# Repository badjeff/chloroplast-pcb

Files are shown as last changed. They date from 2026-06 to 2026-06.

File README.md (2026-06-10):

# chloroplast

A nRF52840 controller with the [Ebyte E73-2G4M08S1C module](https://www.cdebyte.com/products/E73-2G4M08S1C), [TI BQ25186DLHR](https://www.ti.com/product/BQ25186/part-details/BQ25186DLHR), and [TI TPS7A0233PDBVR](https://www.ti.com/product/TPS7A02/part-details/TPS7A0233PDBVR).

<p float="left">
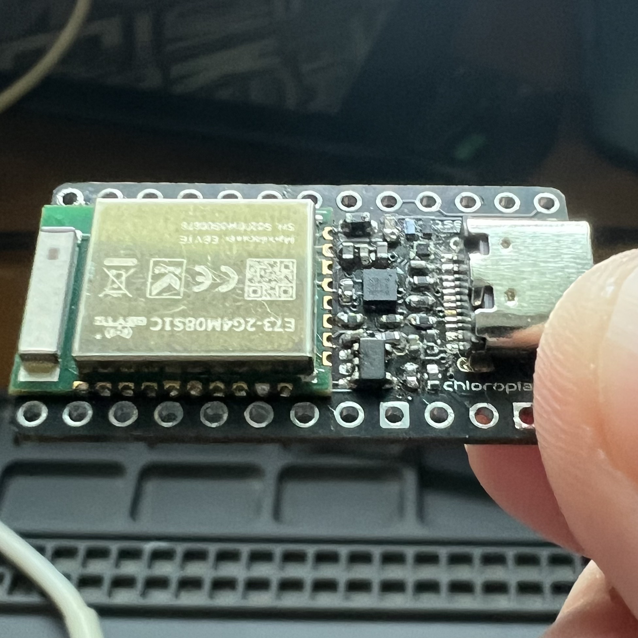
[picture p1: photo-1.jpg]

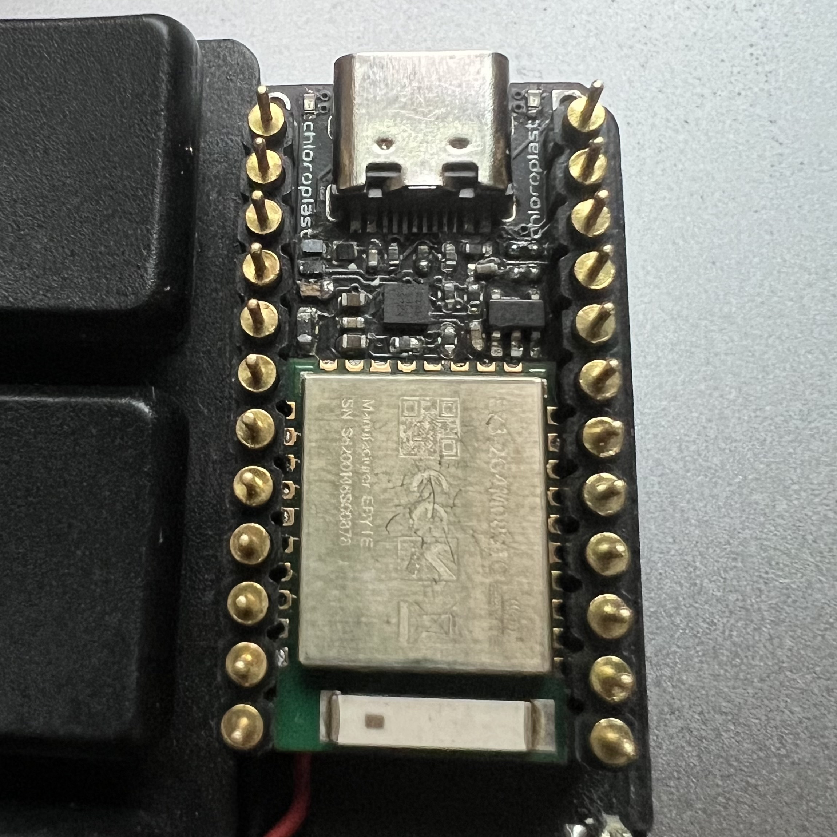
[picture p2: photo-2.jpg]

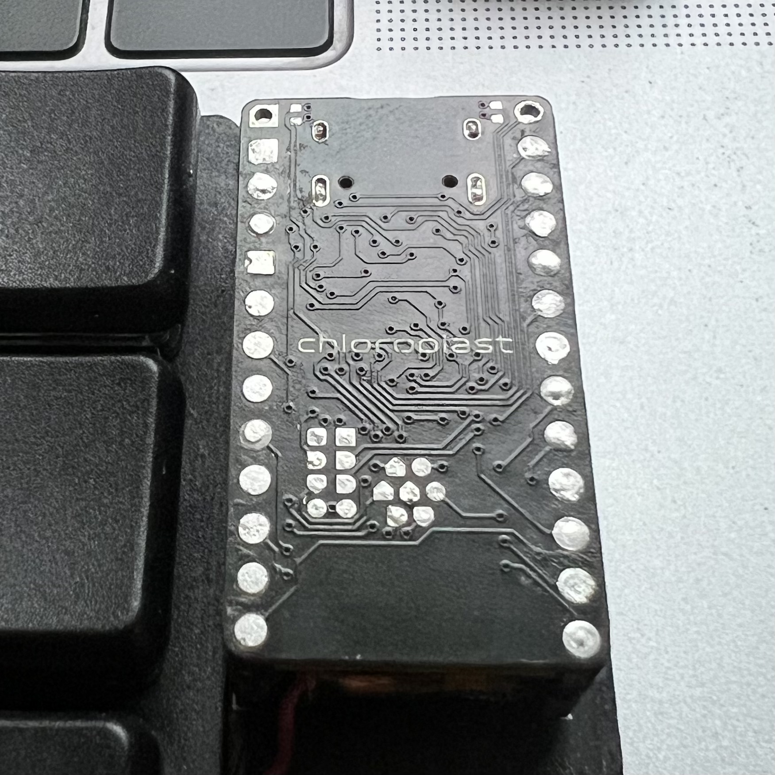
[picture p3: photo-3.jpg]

</p>

## PCB

Online preview avaliable [here](https://kicanvas.org/?github=https%3A%2F%2Fgithub.com%2Fbadjeff%2Fchloroplast-pcb), powered by [KiCanvas](https://github.com/theacodes/kicanvas).

<p float="left">
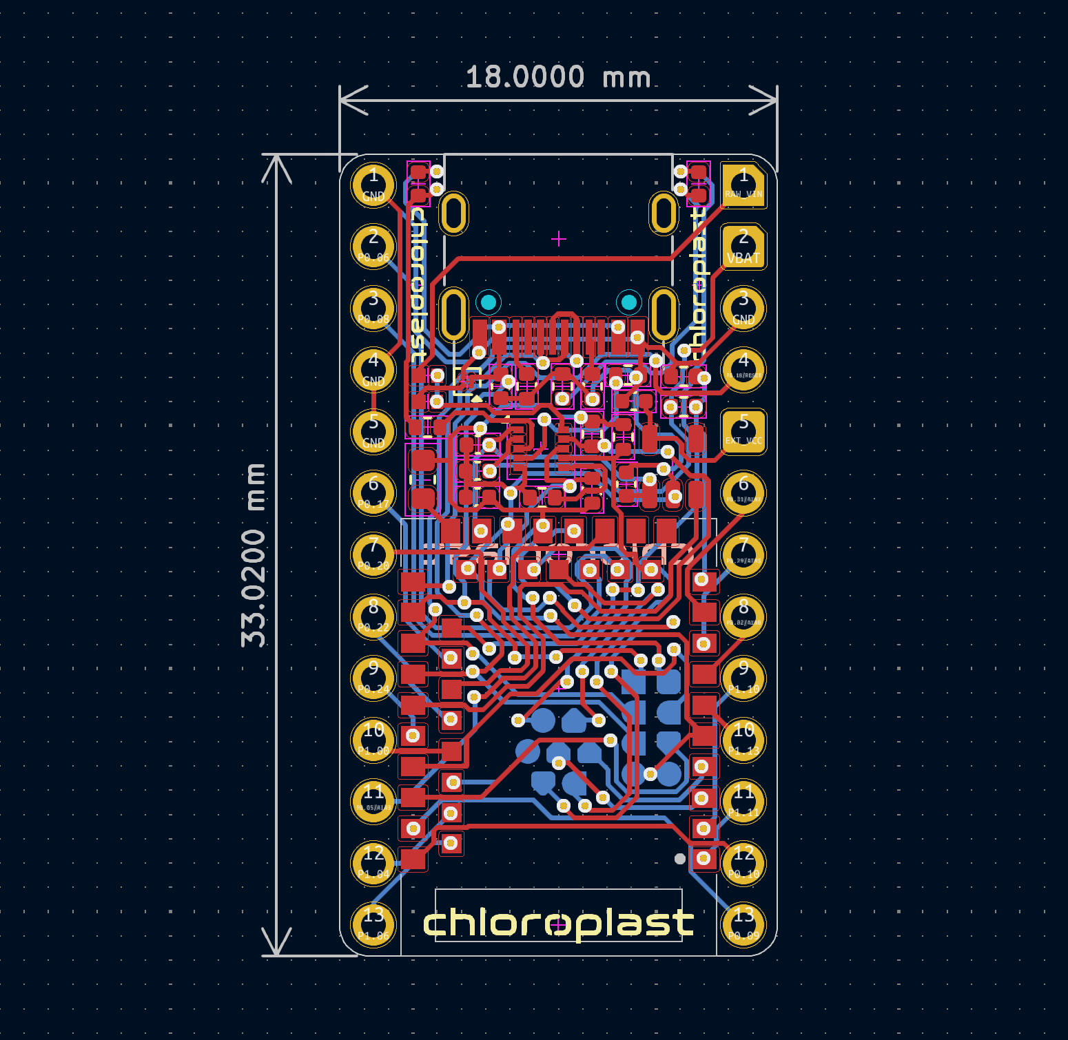
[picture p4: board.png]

</P>

*Figure 1: PCB edgecuts dimension*

<p float="left">
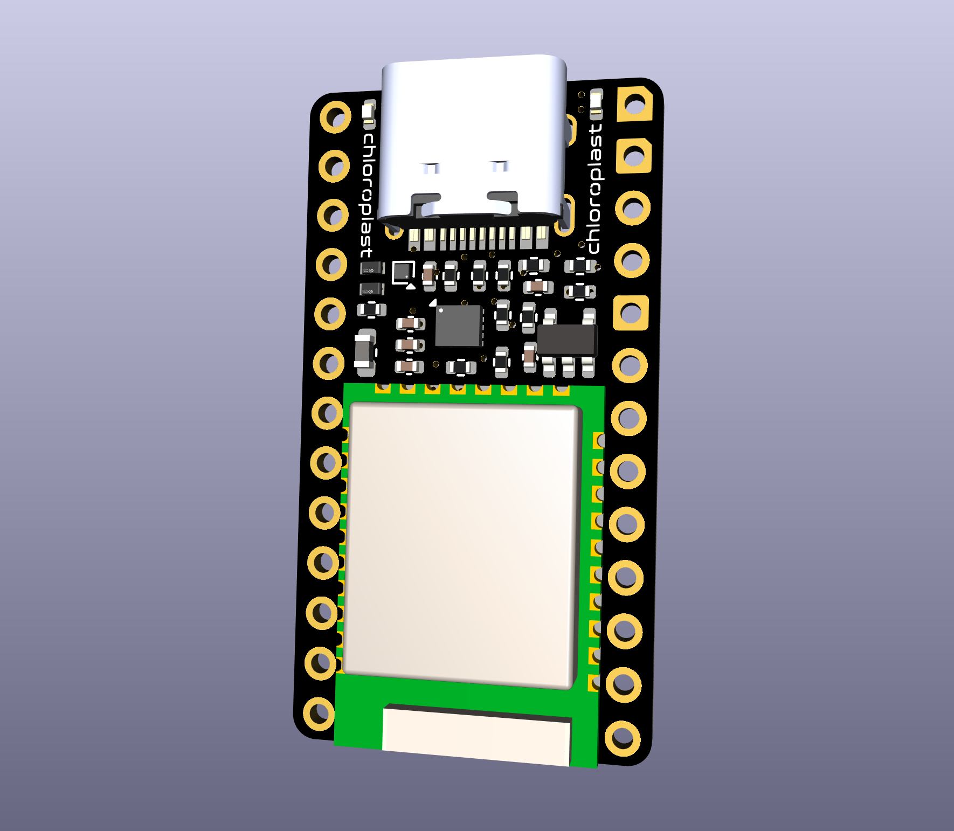
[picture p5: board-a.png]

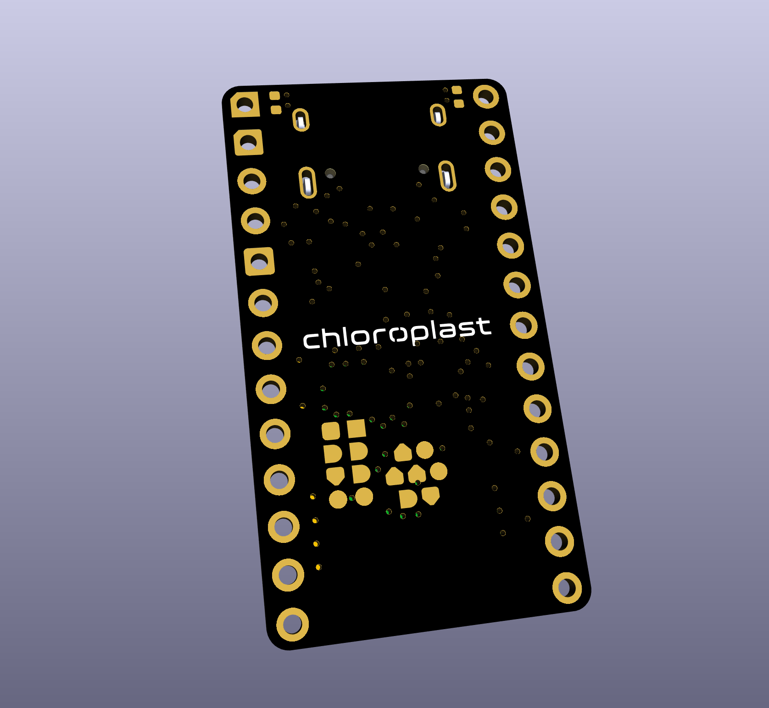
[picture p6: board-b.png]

</p>

*Figure 2: PCB 3D View - 1.0mm FR4*

<p float="left">
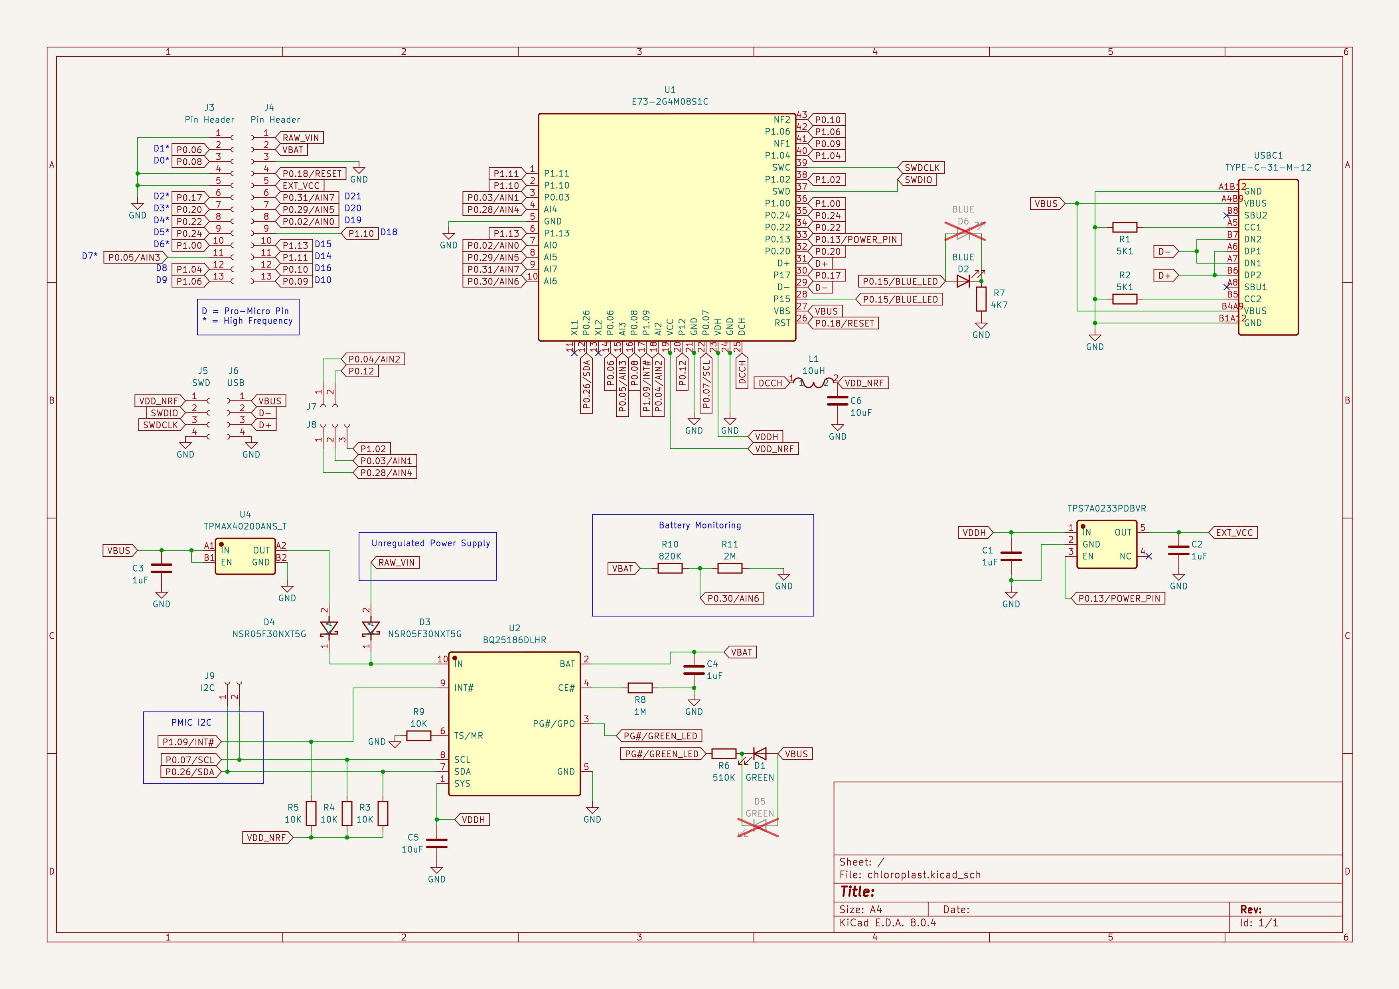
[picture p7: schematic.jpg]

</p>

*Figure 3: Schematic*

### BOM

|Designator|Footprint|Quantity|Value|LCSC Part #|
|-|-|-|-|-|
|C1,C2,C3,C4|0402|4|1uF|C52923|
|C5,C6|0402|2|10uF|C15525|
|D1|0402|1|GREEN LED|C20608784|
|D2|0402|1|BLUE LED|C434447|
|D3,D4|0402|2|NSR05F30NXT5G|C604339|
|L1|0603|1|10uH|C76798|
|R1,R2|0402|2|5K1|C25905|
|R3,R4,R5,R9|0402|4|10K|C25744|
|R6|0402|1|510K|C11616|
|R7|0402|1|4K7|C25900|
|R8|0402|1|1M|C2909328|
|R10|0402|1|820K|C2909386|
|R11|0402|1|2M|C2930015|
|U1|E73-2G4M08S1C|1|E73-2G4M08S1C|C356849|
|U2|DFN-10_2x2mm_P0.4mm|1|BQ25186DLHR|C44639442|
|U3|SOT-23-5|1|TPS7A0233PDBVR|C2887324|
|U4|WLCSP-4L|1|TPMAX40200ANS_T|C47117620|
|USBC1|USB_C_Receptacle|1|TYPE-C-31-M-12|C165948|

- SMD 0402 (Imperial) aka 1005 Metric.
- Alternative LED pads (D5,D6) are layouted on back.

### Board Characteristics

- Copper layer count: 2
- Board thickness: 1.0 mm
- Board overall dimensions: 18.0 x 33.02 mm

### Bootloader

This board uses Adafruit Bootloader. The board folder could be found at [here](https://github.com/adafruit/Adafruit_nRF52_Bootloader/compare/master...badjeff:Adafruit_nRF52_Bootloader:master). Bootloader flashing is recommended to follow the comprehensive guide on [joric/nrfmicro/wiki/Bootloader](https://github.com/joric/nrfmicro/wiki/Bootloader).

### Zephye/ZMK Board Config

Zephyr and ZMK board config could be found in [chloroplast-zmk-module](https://github.com/badjeff/chloroplast-zmk-module). ZMK sheild example could be found in [shields/chlorotaro34](https://github.com/badjeff/zmk-config/tree/a3d11110aed00859894f039f29c2347270b4b8b8/boards/shields/chlorotaro34).

## License

Available under the [CERN-OHL-P v2](/LICENSE) permissive license.

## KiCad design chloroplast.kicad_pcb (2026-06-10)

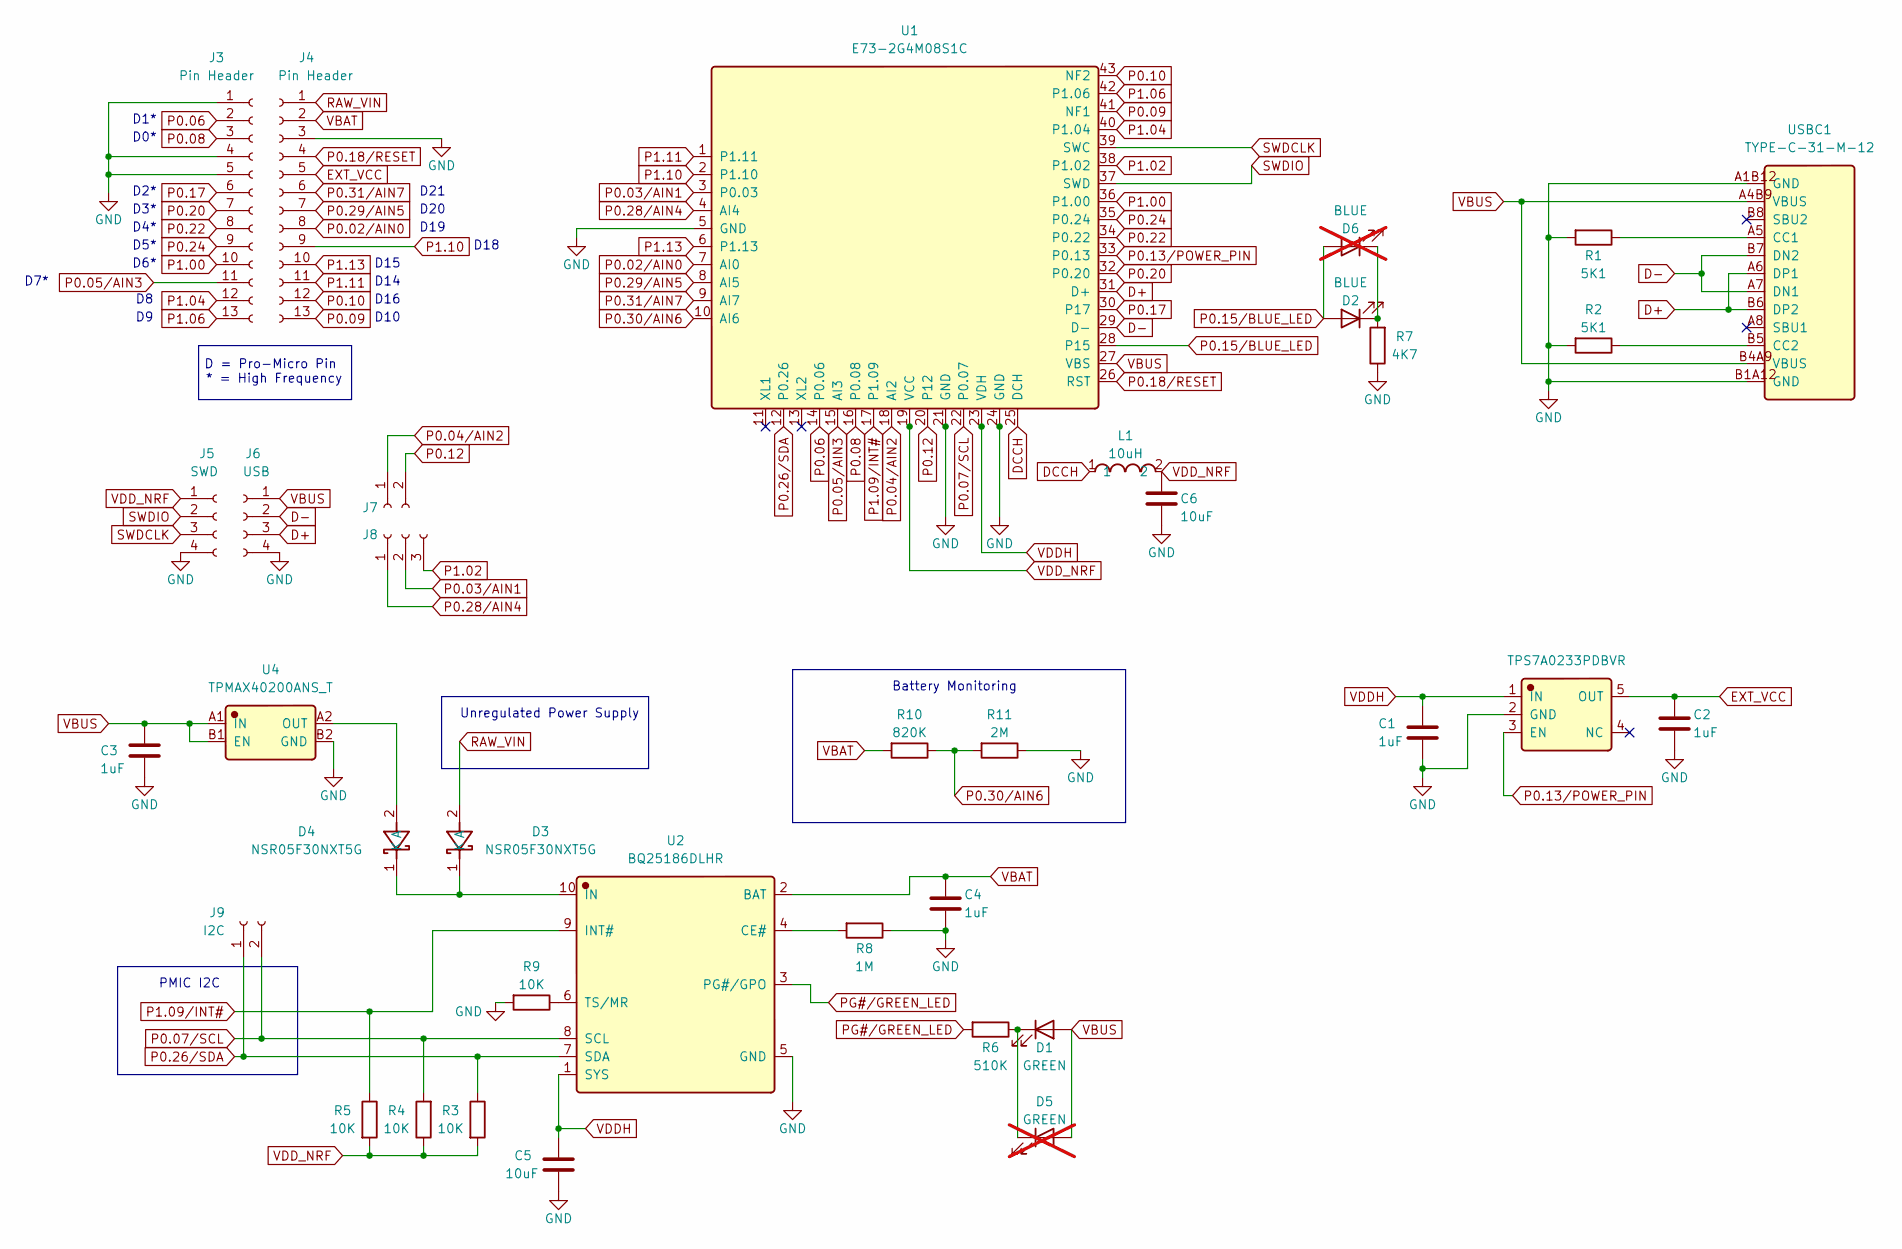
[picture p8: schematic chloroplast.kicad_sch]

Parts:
C1, C2, C3, C4: 1uF; C_0402_1005Metric; LCSC C52923
C5, C6: 10uF; C_0402_1005Metric; LCSC C15525
D1: GREEN; LED_0402_1005Metric; LCSC C20608784
D2: BLUE; LED_0402_1005Metric; LCSC C434447
D3, D4: NSR05F30NXT5G; Manufacturer Part NSR05F30NXT5G; LCSC C604339
D5: GREEN; LED_0402_1005Metric; LCSC C20608784; not fitted
D6: BLUE; LED_0402_1005Metric; LCSC C434447; not fitted
J3, J4: Pin Header; PinHeader_1x13_P2.54mm_Vertical
J5: SWD; PinHeader_1x04_P1.27mm_Vertical
J6: USB; PinHeader_1x04_P1.27mm_Vertical
J7: Conn_01x02_Socket; PinHeader_1x02_P1.27mm_Vertical
J8: Conn_01x04_Socket; PinHeader_1x03_P1.27mm_Vertical
J9: I2C; PinHeader_1x02_P1.27mm_Vertical
L1: 10uH; L_0603_1608Metric; Manufacturer Part MLZ1608M100WT000; LCSC C76798
R1, R2: 5K1; R_0402_1005Metric; LCSC C25905
R3, R4, R5, R9: 10K; R_0402_1005Metric; LCSC C25744
R6: 510K; R_0402_1005Metric; LCSC C11616
R7: 4K7; R_0402_1005Metric; LCSC C25900
R8: 1M; R_0402_1005Metric; LCSC C2909328
R10: 820K; R_0402_1005Metric; LCSC C2909386
R11: 2M; R_0402_1005Metric; LCSC C2930015
U1: E73-2G4M08S1C; Manufacturer Part E73-2G4M08S1C; LCSC C356849
U2: BQ25186DLHR; DFN-10_2x2mm_P0.4mm; Manufacturer Part BQ25186DLHR; LCSC C44639442
U3: TPS7A0233PDBVR; SOT-23-5; Manufacturer Part TPS7A0233PDBVR; LCSC C2887324
U4: TPMAX40200ANS_T; WLCSP-4_0.64x0.64mm_P0.35mm; Manufacturer Part TPMAX40200ANS+T; LCSC C47117620
USBC1: TYPE-C-31-M-12; USB_C_Receptacle_HRO_TYPE-C-31-M-12; Manufacturer Part TYPE-C-31-M-12; LCSC C165948

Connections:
D+: J6.3, U1.31 (D+), USBC1.A6 (DP1), USBC1.B6 (DP2)
D-: J6.2, U1.29 (D-), USBC1.A7 (DN1), USBC1.B7 (DN2)
DCCH: L1.1, U1.25 (DCH)
EXT_VCC: C2.1, J4.5, U3.5 (OUT)
GND: C1.2, C2.2, C3.2, C4.2, C5.2, C6.2, J3.1, J3.4, J3.5, J4.3, J5.4, J6.4, R1.2, R2.2, R7.1, R8.1, R9.2, R11.1, U1.5 (GND), U1.21 (GND), U1.24 (GND), U2.5 (GND), U3.2 (GND), U4.B2 (GND), USBC1.A1B12 (GND), USBC1.B1A12 (GND)
unnamed: D1.1 (K), D5.1 (K), R6.1
unnamed: D2.1 (K), D6.1 (K), R7.2
unnamed: D3.1 (K), D4.1 (K), U2.10 (IN)
unnamed: D4.2 (A), U4.A2 (OUT)
unnamed: R8.2, U2.4 (CE#)
unnamed: R9.1, U2.6 (TS/MR)
unnamed: R1.1, USBC1.A5 (CC1)
unnamed: R2.1, USBC1.B5 (CC2)
P0.02/AIN0: J4.8, U1.7 (AI0)
P0.03/AIN1: J8.2, U1.3 (P0.03)
P0.04/AIN2: J7.1, U1.18 (AI2)
P0.05/AIN3: J3.11, U1.15 (AI3)
P0.06: J3.2, U1.14 (P0.06)
P0.07/SCL: J9.2, R4.2, U1.22 (P0.07), U2.8 (SCL)
P0.08: J3.3, U1.16 (P0.08)
P0.09: J4.13, U1.41 (NF1)
P0.10: J4.12, U1.43 (NF2)
P0.12: J7.2, U1.20 (P12)
P0.13/POWER_PIN: U1.33 (P0.13), U3.3 (EN)
P0.15/BLUE_LED: D2.2 (A), D6.2 (A), U1.28 (P15)
P0.17: J3.6, U1.30 (P17)
P0.18/RESET: J4.4, U1.26 (RST)
P0.20: J3.7, U1.32 (P0.20)
P0.22: J3.8, U1.34 (P0.22)
P0.24: J3.9, U1.35 (P0.24)
P0.26/SDA: J9.1, R3.1, U1.12 (P0.26), U2.7 (SDA)
P0.28/AIN4: J8.1, U1.4 (AI4)
P0.29/AIN5: J4.7, U1.8 (AI5)
P0.30/AIN6: R10.1, R11.2, U1.10 (AI6)
P0.31/AIN7: J4.6, U1.9 (AI7)
P1.00: J3.10, U1.36 (P1.00)
P1.02: J8.3, U1.38 (P1.02)
P1.04: J3.12, U1.40 (P1.04)
P1.06: J3.13, U1.42 (P1.06)
P1.09/INT#: R5.1, U1.17 (P1.09), U2.9 (INT#)
P1.10: J4.9, U1.2 (P1.10)
P1.11: J4.11, U1.1 (P1.11)
P1.13: J4.10, U1.6 (P1.13)
PG#/GREEN_LED: R6.2, U2.3 (PG#/GPO)
RAW_VIN: D3.2 (A), J4.1
SWDCLK: J5.3, U1.39 (SWC)
SWDIO: J5.2, U1.37 (SWD)
VBAT: C4.1, J4.2, R10.2, U2.2 (BAT)
VBUS: C3.1, D1.2 (A), D5.2 (A), J6.1, U1.27 (VBS), U4.A1 (IN), U4.B1 (EN), USBC1.A4B9 (VBUS), USBC1.B4A9 (VBUS)
VDDH: C1.1, C5.1, U1.23 (VDH), U2.1 (SYS), U3.1 (IN)
VDD_NRF: C6.1, J5.1, L1.2, R3.2, R4.1, R5.2, U1.19 (VCC)

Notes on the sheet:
Unregulated Power Supply
D20
D19
D18
Battery Monitoring
D21
D14
D6*
D15
D5*
D3*
D16
D1*
D = Pro-Micro Pin * = High Frequency
D4*
D0*
D2*
D10
PMIC I2C
D7*

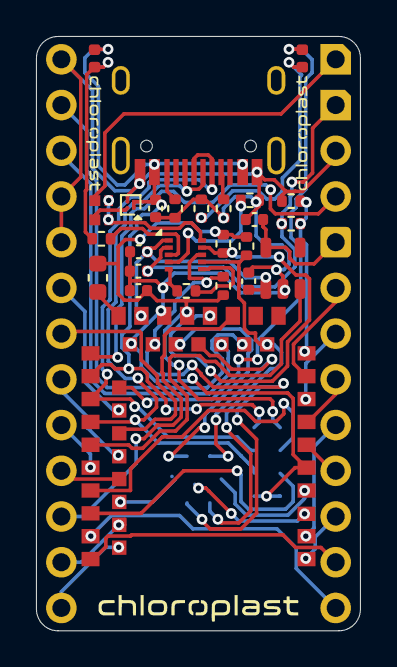
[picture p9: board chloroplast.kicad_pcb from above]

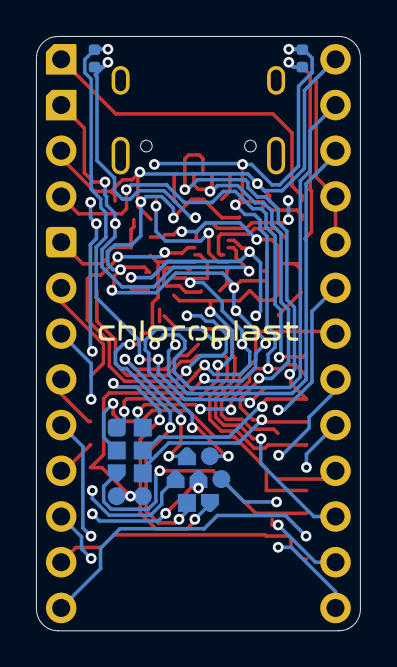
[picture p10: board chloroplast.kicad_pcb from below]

Board: 2 copper layers, 18.0 x 33.0 mm, 36 parts (7 on the bottom side), 51 nets.

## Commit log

2026-06-04 add pro-micro pin numbers in schematic
    [chloroplast.kicad_sch]
2026-06-10 change L1 to TDK MLZ1608M100WT000
    [chloroplast.kicad_pcb, chloroplast.kicad_sch]
